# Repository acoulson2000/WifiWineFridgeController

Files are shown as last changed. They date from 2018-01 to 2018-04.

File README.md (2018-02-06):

# WifiWineFridgeController

This project comprises two sketches for Wifi-Enabling my peltier-cooled wine refrigerator and for regulating the
temperature by managing the power supplied to the Fan/Peltier thermocouple assemblies.

WineFridgeWifi.ino is intended to run on a Heltec "Wifi Kit 8" ESP8266 + 96x32 OLED board, which acts as the
"front-end" controller. It could be adapted to other ESP8266 + OLED combinations relatively easily. This sketch
provides a web interface for displaying and setting the fridge temps (with the option to have button-controlled
setting, as well), displays the temp, and sends the setting to an Arduino/Monster Moto shield combo on the backend
periodically over serial2 (provided via the SoftwareSerial lib).

The Arduino back-end regulates power to the fans and peltier heat sinks by varying the duty cycle of PWM pins connected
to a Monster Moto shield. WineCoolerDriver.ino is intended for the Arduino. It handles sensing the current temperature, 
which it sends back to the front-end periodically over serial2, and varying the PWM duty cycle base on the differnce
between the current and target temperatures.

Various debugging and diagnostics are printed on SERIAL by both sketches.

Much more detail is available on my blog post at:
 https://austinlightguy.wordpress.com/2018/02/06/wine-fridge-temperature-controller-v2/
 
Info on the my original effort, which was just to replace the proprietary power supply that burned out,
can be found on an earlier post here: https://austinlightguy.wordpress.com/2016/04/26/wine-cooler-power-supply/

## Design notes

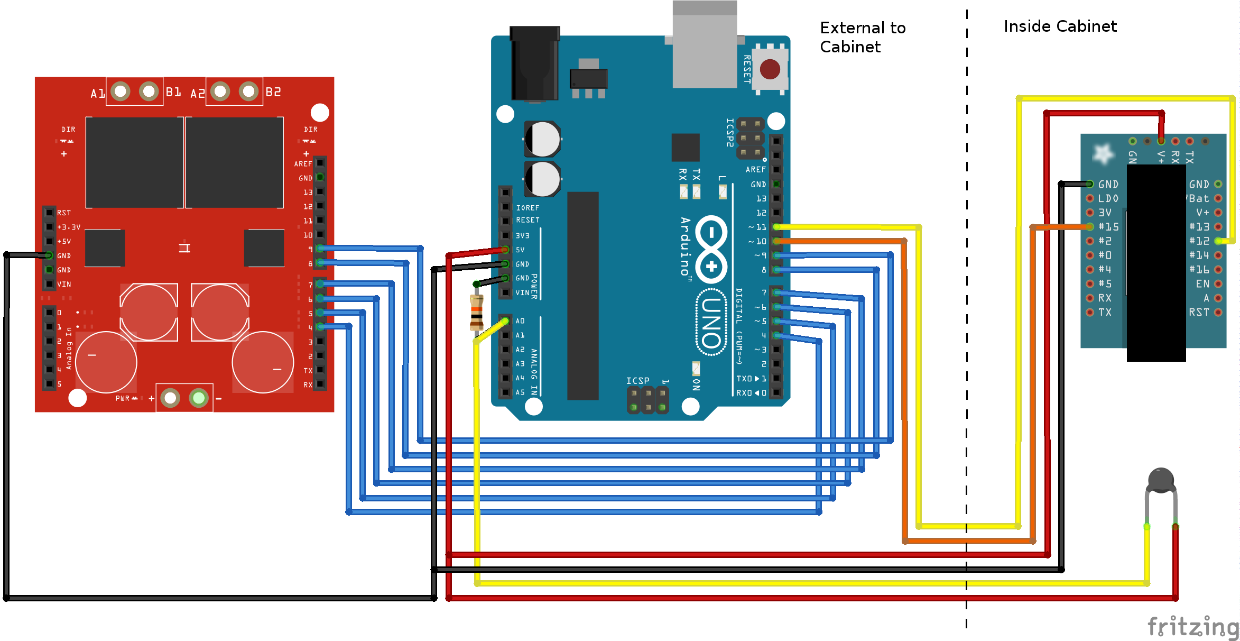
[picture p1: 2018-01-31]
WineCoolerDriver/Fritzing.png

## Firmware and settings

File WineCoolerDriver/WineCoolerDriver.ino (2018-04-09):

#include <SoftwareSerial.h>
#include <math.h>

#define NUMSAMPLES 10

// PWM_BASE been tuned to provide a base level of cooling which seems necessary to maintain a
// constant temperature when set to a reasonable level and external ambient temp is room temperature.
// PWM_INCREMENT is multplied by the diff between current temp and target setpoint, then added
// to PWM_BASE - so if you have a difference >= 3.4°, PWM will be running at max (255). This will
// gradually reduce as the temp difference decrease, down to a minimum of PWM_MIN.
#define PWM_BASE 150
#define PWM_INCREMENT 50
#define PWM_MIN 100         // Set to minimum PWM duty cycle - Don't make it too low, since we want the power supply fan to run at a minimum level
    
#define CW   1
#define CCW  2
#define CS_THRESHOLD 100
  
// We use serial2 to communicate with the head unit. It requires the SoftwareSerial lib and uses any two
// available pins.
SoftwareSerial serial2(10, 11); // RX, TX

int tempSetPoint = 60;
int temp = 60;
float movingAverage;
int samples[NUMSAMPLES];

/*  VNH2SP30 (Monster Moto shield) pin definitions
 xxx[0] controls '1' outputs
 xxx[1] controls '2' outputs */
int inApin[2] = {7, 4};  // INA: Clockwise input
int inBpin[2] = {8, 9}; // INB: Counter-clockwise input
int pwmpin[2] = {5, 6}; // PWM input

int THERMISTOR_PIN  = A0;                 // Analog Pin 0

int statpin = 13;

int pwm = 0;
int stat = LOW;
byte ack = 0;

// Sample code cribbed from interwebs didn't seem to produce legit results - possibly since
// I don't know what device is used as the sensor in the wine cooler. So, instead, I took
// measurements of ADC values and cross-referenced them to measured actual temps in a 
// trend-line in Excel. That gav eme a very good linear trend line, and I can use the
// slope of it to calculate reasonable temps. The values in this function are based on
// the slope of that line.
float trendBaseADC = 830; // My trend line started at ADC 830
float trendBaseTemp = 60; // My trend line started at ADC 830
float baseAdcDelta = 43.5; // An ADC delta of -43.5 resulted in a temp decrease of 12.2
float baseTempDelta = 12.2;

float Thermistor(int RawADC) {
  float calulatedTemp = trendBaseTemp - ((RawADC - trendBaseADC) / baseAdcDelta * baseTempDelta);  
  //Serial.print("RawADC: "); 
  //Serial.print(RawADC); 
  //Serial.print("calulatedTemp: "); 
  //Serial.print(calulatedTemp); 
  //Serial.println(""); 
  return calulatedTemp;                                      // Return the Temperature
}

void setup() {
  Serial.begin(115200);
  serial2.begin(115200);

  analogReference(DEFAULT);
  
  pinMode(statpin, OUTPUT);
 
  // Initialize digital pins as outputs
  for (int i=0; i<2; i++)
  {
    pinMode(inApin[i], OUTPUT);
    pinMode(inBpin[i], OUTPUT);
    pinMode(pwmpin[i], OUTPUT);
  }

  movingAverage = temp;
}

int ch;

void loop() {
  bool gotNewTemp = false;
  // Check for temp setting from head unit
  while (serial2.available() > 0) {
    ch = serial2.read();
    Serial.print("got: ");
    Serial.println(ch, DEC);
    if (ch == 0) {  // ping
      ack = pwm;
      serial2.write(ack);
      serial2.println("OK");
    } else {
      gotNewTemp = true;
    }
  }
  // If we got a temp setting and it's within reasonable bounds, use it and log it.
  if (gotNewTemp && ch > 32 && ch < 80) {
    tempSetPoint = ch;
    Serial.print("Set temp to: ");
    Serial.println(ch, DEC);
  }
  // We can also take settings over primary Serial port for debugging
  if (Serial.available() > 0) {
    Serial.print("Set temp to: ");
    int ch = Serial.read();
    Serial.println(ch, DEC);
    if (ch > 32 && ch < 80) {
      tempSetPoint = ch;
    }
  }

  // Toggle status LED
  if (stat == LOW) {
    stat = HIGH;
  } else {
    stat = LOW;
  }
  digitalWrite(statpin, stat);

  uint8_t i;
  float average;
 
  // take N samples in a row, with a slight delay
  for (i=0; i< NUMSAMPLES; i++) {
    samples[i] = Thermistor(analogRead(THERMISTOR_PIN)); 
    delay(100);
  }
 
  // average NUMSAMPLES samples out to get a moving average and smoother PWM transitions
  average = 0;
  for (i=0; i< NUMSAMPLES; i++) {
    average += samples[i];
  }
  average /= NUMSAMPLES;

  Serial.print("Latest reading°F: "); 
  Serial.print(average);
  
  movingAverage = ((movingAverage * 19) + average) / 20;
  average = movingAverage;

  temp = (int) (average + .5);	// round up for display

  Serial.print(" Smoothed°F: "); 
  Serial.print(average);
  Serial.print(" Target°F: "); 
  Serial.print(tempSetPoint);

  // Determine PWM duty cycle and set it on the two Moto PWM pins
  float diff = average - (float)tempSetPoint;
  Serial.print(" pwm adj: "); 
  Serial.print(diff);
  pwm = PWM_BASE + (PWM_INCREMENT * diff);
  if (pwm < PWM_MIN) pwm = PWM_MIN;
  if (pwm > 255) pwm = 255;
  motorGo(0, CCW, pwm);
  motorGo(1, CCW, pwm);

  Serial.print(" PWM: "); 
  Serial.println(pwm);

  serial2.write(temp);                  // send temp to ESP8266
  
  delay(3000);
}


// This is from an example for driving the Moto shield for motor control.
// We only use it in one polarity (counterclockwise), although I suppose you
// could theoretically tweak things a bit to run in reverse and it might WARM
// the fridge :-)

/* motorGo() will set a motor going in a specific direction
 the motor will continue going in that direction, at that speed
 until told to do otherwise.
 
 motor: this should be either 0 or 1, will selet which of the two
 motors to be controlled
 
 direct: Should be between 0 and 3, with the following result
 0: Brake to VCC
 1: Clockwise
 2: CounterClockwise
 3: Brake to GND
 
 pwm: should be a value between ? and 1023, higher the number, the faster
 it'll go
 */
void motorGo(uint8_t motor, uint8_t direct, uint8_t pwm)
{
  if (motor <= 1)
  {
    if (direct <=4)
    {
      // Set inA[motor]
      if (direct <=1)
        digitalWrite(inApin[motor], HIGH);
      else
        digitalWrite(inApin[motor], LOW);

      // Set inB[motor]
      if ((direct==0)||(direct==2))
        digitalWrite(inBpin[motor], HIGH);
      else
        digitalWrite(inBpin[motor], LOW);

      analogWrite(pwmpin[motor], pwm);
    }
  }
}

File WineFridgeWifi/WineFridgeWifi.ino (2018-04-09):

/*
 * Required libraries:
 * 
 * ArduinoJson:   https://github.com/bblanchon/ArduinoJson
 * WiFiManager:   https://github.com/tzapu/WiFiManager
 * Adafruit_GFX:  https://github.com/adafruit/Adafruit-GFX-Library
 * Adafruit_SSD1306: https://github.com/adafruit/Adafruit_SSD1306
 * SoftwareSerial:  (ESP version) https://github.com/plerup/espsoftwareserial
 * 
 * This is a sketch for the front-end controller of the wine refrigerator. 
 * It is intended to run on a Heltec "WIfi Kit 8" ESP8266 + 96x32 OLED board, but could 
 * be adapted to other ESP8266 + OLED compbinations. It provides a web interface
 * for displaying and setting the fridge temps (with the option to have button-controlled
 * settings, as well), displays the temp, and sends the setting to an Arduino/Monster
 * Moto shield combo on the backend which drive power ti the fans and peltier heat sinks. 
 * It sends the target temp to the Arduino periodically over serial2. The Arduino
 * also senses the current temp, which it sends back to this front-end periodically
 * over serial2.  Various debugging and diagnostics are printed on SERIAL.
 */
#include <SPI.h>
#include <Wire.h>
#include <SoftwareSerial.h>
#include <Adafruit_GFX.h>         //For rendering to Heltec OLED screen (uses SSD1306 chip)
#include <Adafruit_SSD1306.h>

#include <FS.h>                   //this needs to be first, or it all crashes and burns...

#include <ESP8266WiFi.h>          //https://github.com/esp8266/Arduino


#include <DNSServer.h>            //needed for WiFiManager
#include <ESP8266WebServer.h>
#include <WiFiManager.h>          //https://github.com/tzapu/WiFiManager
#include "html.h"                 //Part of project - strings for http server responses

#include <ArduinoJson.h>          //https://github.com/bblanchon/ArduinoJson
#include "user_interface.h"

#define SERIAL2_RX 12
#define SERIAL2_TX 15
#define OLED_RESET 16 // override necessary to make OLED on Wifi Kit 8 work
#define CONFIG_PORTAL_TIMEOUT 60 // how long to stay in config mode on boot-up
// You can optionaly have buttons to control the temp setting in addition to WiFi.
// If so, set the pin numbers for the temp increase and decrease buttons here.
// (pull low when pressed)
int GPIO_TEMP_DOWN = 14;
int GPIO_TEMP_UP = 13;

//define default startup values here. Target setpoint is written to config.json in the SPIFFS
//file system after being set. After being set once, that value will override the ones here
//on boot. The current temp will be set periodically when received from the Arduino fan controller.
unsigned int fridgeTempCurrent = 60;
unsigned int fridgeTempSetpoint = 60;
char Temp_Setpoint[3] = "60";
unsigned int pwmVal = 0;
boolean ackOK = false;

Adafruit_SSD1306 display(OLED_RESET);

SoftwareSerial serial2(SERIAL2_RX, SERIAL2_TX, false, 256);

// Image byte arrays for rendering wifi available/unavailable symbols
static const uint8_t wifi_connected[] = {
0x0,0x0,0x7,0xc0,0x1f,0xf0,0x3f,0xf8,0x7f,0xfc,0x3f,0xf8,0x1f,0xf0,0xf,0xe0,0x7,0xc0,0x3,0x80,0x1,0x0,0x0,0x0
};
static const uint8_t wifi_broken[] = {
0x00, 0x10, 0x38, 0x7C, 0xFC, 0xFE, 0xFE, 0xC2, 0xFE, 0xFE, 0xFC, 0x7C, 0x38, 0x10, 0x00, 0x00, 0x00, 0x00, 0x00, 0x00, 
0x01, 0x03, 0x06, 0x03, 0x01, 0x00, 0x00, 0x00, 0x00, 0x00
};

char* CONFIG_AP = "ESPFridge";    //Set to your preference - Available to connect to when WiFiManager is in config mode

char jsonValueBuffer[3];
char stringBuffer[64];
int lastMillis = millis();

std::unique_ptr<ESP8266WebServer> server;

void handleRoot() {
  Serial.println("handle root");
  sprintf(stringBuffer, "ESPFridge Temp:%d  Target Temp:%d.", fridgeTempCurrent, fridgeTempSetpoint);
  String indexHtml = MAIN_page;
  String sTemp = String(fridgeTempCurrent, DEC);
  indexHtml.replace("{{temp}}", sTemp);
  indexHtml.replace("{{targetTemp}}", Temp_Setpoint);
  server->send(200, "text/html", indexHtml);
}

void handleSetTemp() {
  Serial.println("handle settemp");
  String pTemp = server->arg("temp");
  Serial.print("set temp=");
  Serial.println(pTemp);
  pTemp.toCharArray(Temp_Setpoint, 3);
  Serial.print("char[]=");
  Serial.println(Temp_Setpoint);
  fridgeTempSetpoint = atoi(Temp_Setpoint);
  Serial.print("send temp to controller:");
  Serial.println(fridgeTempSetpoint,DEC);
  serial2.write(fridgeTempSetpoint);
  saveConfig();
  server->send(200, "text/html", "set temp=" + String(Temp_Setpoint));
}

void handleStatus() {
  Serial.println("handle status");
  sprintf (stringBuffer, "{currentTemp=\"%d\", targetTemp=\"%d\"}", fridgeTempCurrent, fridgeTempSetpoint);
  server->send(200, "text/json", stringBuffer);
}

void handleReboot() {
  Serial.println("handle reboot");
  server->send(200, "text/plain", "Rebooting...");
  ESP.restart();
  delay(5000);  
}

void handleNotFound() {
  Serial.println("handle not found:");
  Serial.println(server->uri());
  String message = "File Not Found\n\n";
  message += "URI: ";
  message += server->uri();
  message += "\nMethod: ";
  message += (server->method() == HTTP_GET) ? "GET" : "POST";
  message += "\nArguments: ";
  message += server->args();
  message += "\n";
  for (uint8_t i = 0; i < server->args(); i++) {
    message += " " + server->argName(i) + ": " + server->arg(i) + "\n";
  }
  server->send(404, "text/plain", message);
}

  void saveConfig() {
  //save the custom parameters to FS
    Serial.println("saving config");
    DynamicJsonBuffer jsonBuffer;
    JsonObject& json = jsonBuffer.createObject();
    json["temp_setpoint"] = Temp_Setpoint;

    File configFile = SPIFFS.open("/config.json", "w");
    if (!configFile) {
      Serial.println("failed to open config file for writing");
    }

    json.printTo(Serial);
    json.printTo(configFile);
    configFile.close();
    Serial.println();
    //end save
  }
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

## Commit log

2018-02-01 Tweaked PWM base and scaling
2018-02-06 Add comments, better sensor averaging, reboot link on home page.
    [WineCoolerDriver.ino, WineFridgeWifi.ino]
2018-04-07 Add acknowledgment and pwm feedback, adjusted offset multiplyer
2018-04-09 Added power level display
